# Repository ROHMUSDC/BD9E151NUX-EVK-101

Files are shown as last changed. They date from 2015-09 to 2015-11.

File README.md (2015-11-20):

# BD9E151NUX-EVK-101 Design Resource Repository
* Hardware Design Files and Documentation for the ROHM BD9E151NUX-EVK-101 EVK

----
### Description: 
* BD9E151NUX is a 28Vin max, 1.2A diode-rectification buck converter that integrated internal high-side 30V Power MOSFET
* To increase efficiency at light loads, a pulse skipping mode is automatically activated
* Furthermore, the 0uA shutdown supply current allows the device to be used in battery powered applications
* Current mode control with internal slope compensation simplifies the external component count while allowing the use of ceramic output capacitors

----
### Repository Contents
* Application Note Folder: Contains Draft Version of EVK Application Note
* Design Files: Contains Board, Gerber, Schematic, and BOM information for this EVK Board
* Measurement Reports Folder: Contains measurement testing information completed for these EVK Boards

----
### Where to Purchase?
* http://www.rohm.com/web/global/distribution/-/dinventory/BD9E151NUX-TR/sample/0

----
### DISCLAIMER
This Technical Data is protected under copyright laws.

ROHM hereby grants you a nonexclusive, nontransferable license to use this Technical Data 
as long as you abide by the terms and conditions of this DISCLAIMER. 

However, you are not authorized to sell, loan, rent, lease, redistribute or license this Technical Data, 
in whole or in part, or in modified form, to anyone.

You may modify this Technical Data to suit your specific applications, 
but the rights to derivative works and said modifications shall belong to ROHM. 

You may make copies of this Technical Data as necessary for internal use only within your company.

In any case, the latest datasheet is considered the final design guideline and represents 
the only actual performance specifications.

ROHM shall not be responsible for ensuring proper application on all computer systems.
This Technical Data is provided AS IS. ROHM makes no guarantees, either implicitly or explicitly, 
regarding its usability, functionality, accuracy, merchantability, or fitness for a specific purpose.

In addition, you shall take full responsibility for the use of any information acquired from this Technical Data. 

ROHM does not assume warranty of any kind arising from the use of this Technical Data. ACCORDINGLY, 
IN NO EVENT SHALL ROHM BE RESPONSIBLE, WHETHER THROUGH CONTRACT OR TORT LIABILITY, 
FOR ANY DAMAGES (INCLUDING BUT NOT LIMITED TO LOST PROFITS OR OTHER INCIDENTAL, CONSEQUENTAL, 
OR PUNITIVE DAMAGES) ARISING OUT OF OR IN CONNECTION WITH THE USE OR APPLICATION OF THIS Technical Data.

Furthermore, this Technical Data is subject to change without notice.

Unless otherwise expressly provided herein, ROHM does not convey any license under patent rights 
or any other intellectual property rights (including those of third parties).

ROHM is not obligated to provide maintenance or support for the Technical Data.

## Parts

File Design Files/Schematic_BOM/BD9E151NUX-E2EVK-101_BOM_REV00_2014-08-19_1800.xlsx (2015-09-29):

TITLE & REVISION HISTORY Revised: Tuesday, August 19, 2014
xxxxx Revision: 00
Bill Of Materials August 19,2014 14:56:44 | Page1
Item | Quantity | Reference | Part | PCB Footprint | DESCRIPTION | MANUFACTURER1 | MANUFACTURER1_PART# | DISTR1 | DISTR1_PART# | DNP | Provided by ROHM | Comment
1 | 1 | C1 | 0.1uF | C0603 | CAP CER 0.1UF 16V 10% X7R 0603 | Murata | GRM188R71C104KA01D | DIGIKEY | 490-1532-2-ND |  | N | Contact Murata to get free parts
2 | 2 | C2,C3 | 22uF | C1210 | CAP CER 22UF 16V 20% X7R 1210 | Murata | GRM32ER71C226ME18L | DIGIKEY | 490-4740-2-ND |  | N | Contact Murata to get free parts
3 | 1 | C6 | 10uF | C1206 | CAP CER 10UF 35V 10% X5R 1206 | Murata | GRM31CR6YA106KA12L | DIGIKEY | 490-5524-1-ND |  | N | Contact Murata to get free parts
4 | 1 | C8 | 10000pF | C0402 | CAP CER 10000PF 50V 10% X7R 0402 | Murata | GRM155R71H103KA88D | DIGIKEY | 490-4516-1-ND |  | N | Contact Murata to get free parts
5 | 1 | C9 | 0.047uF | C0402 | CAP CER 0.047UF 25V 10% X7R 0402 | Murata | GRM155R71E473KA88D | DIGIKEY | 490-3254-1-ND |  | N | Contact Murata to get free parts
6 | 1 | D1 | RSX101VA-30TR | TUMD2 | DIODE SCHOTTKY 30V 1A 2TUMD | ROHM | RSX101VA-30TR | DIGIKEY | RSX101VA-30CT-ND |  | Y
7 | 1 | D2 | SMAJ26A | DO-214AC | TVS DIODE 26VWM 42.1VC SMA | Littelfuse Inc | SMAJ26A | DIGIKEY | SMAJ26ALFCT-ND |  | N
8 | 1 | J1 | 68000-103HLF | HDR_THVT_1X3_100 | CONN HEADER VERT .100 3POS 15AU | FCI | 68000-103HLF | DIGIKEY | 609-3461-ND |  | N
9 | 1 | L1 | 15uH | SMT_10Mx10M | INDUCTOR POWER 15UH 2.2A SMD | Wurth Electronics | 7447713150 | DIGIKEY | 732-2978-6-ND |  | N | Contact WE to get free parts
10 | 1 | R1 | 12K | R0603 | RES 12K OHM 1/10W 1% 0603 SMD | ROHM | MCR03ERTF1202 | DIGIKEY | RHM12.0KCLTR-ND |  | Y
11 | 1 | R2 | 3K | R0603 | RES 3K OHM 1/10W 1% 0603 SMD | ROHM | MCR03ERTF3001 | DIGIKEY | RHM3.00KCFTR-ND |  | Y
12 | 1 | R3 | 2.7K | R0603 | RES 2.7K OHM 1/10W 1% 0603 SMD | ROHM | MCR03ERTF2701 | DIGIKEY | RHM2.7KCFDKR-ND |  | Y
13 | 2 | TP1,TP3 | TP_TH_63MIL_RED | TP_TH | TEST POINT PC MULTI PURPOSE RED | Keystone Electronics | 5010 | DIGIKEY | 5010K-ND |  | N
14 | 2 | TP2,TP4 | TP_TH_63MIL_BLK | TP_TH | TEST POINT PC MULTI PURPOSE BLK | Keystone Electronics | 5011 | DIGIKEY | 5011K-ND |  | N
15 | 1 | U1 | BD9E151NUX | VSON008X2030 | IC REG BUCK ADJ 1.2A 8VSON | ROHM | BD9E151NUX-TR | DIGIKEY | BD9E151NUXDKR-ND |  | Y
16 | 1 |  |  |  | Shunt jumper for header J1 (item #8), CONN SHUNT 2POS GOLD W/HANDLE | TE Connectivity | 881545-1 | DIGIKEY | 881545-1-ND |  | N
17 | 2 | C4,C7 |  | C0603 |  |  |  |  |  | DNP( Do Not Place)
18 | 1 | C5 |  | C0805 |  |  |  |  |  | DNP( Do Not Place)

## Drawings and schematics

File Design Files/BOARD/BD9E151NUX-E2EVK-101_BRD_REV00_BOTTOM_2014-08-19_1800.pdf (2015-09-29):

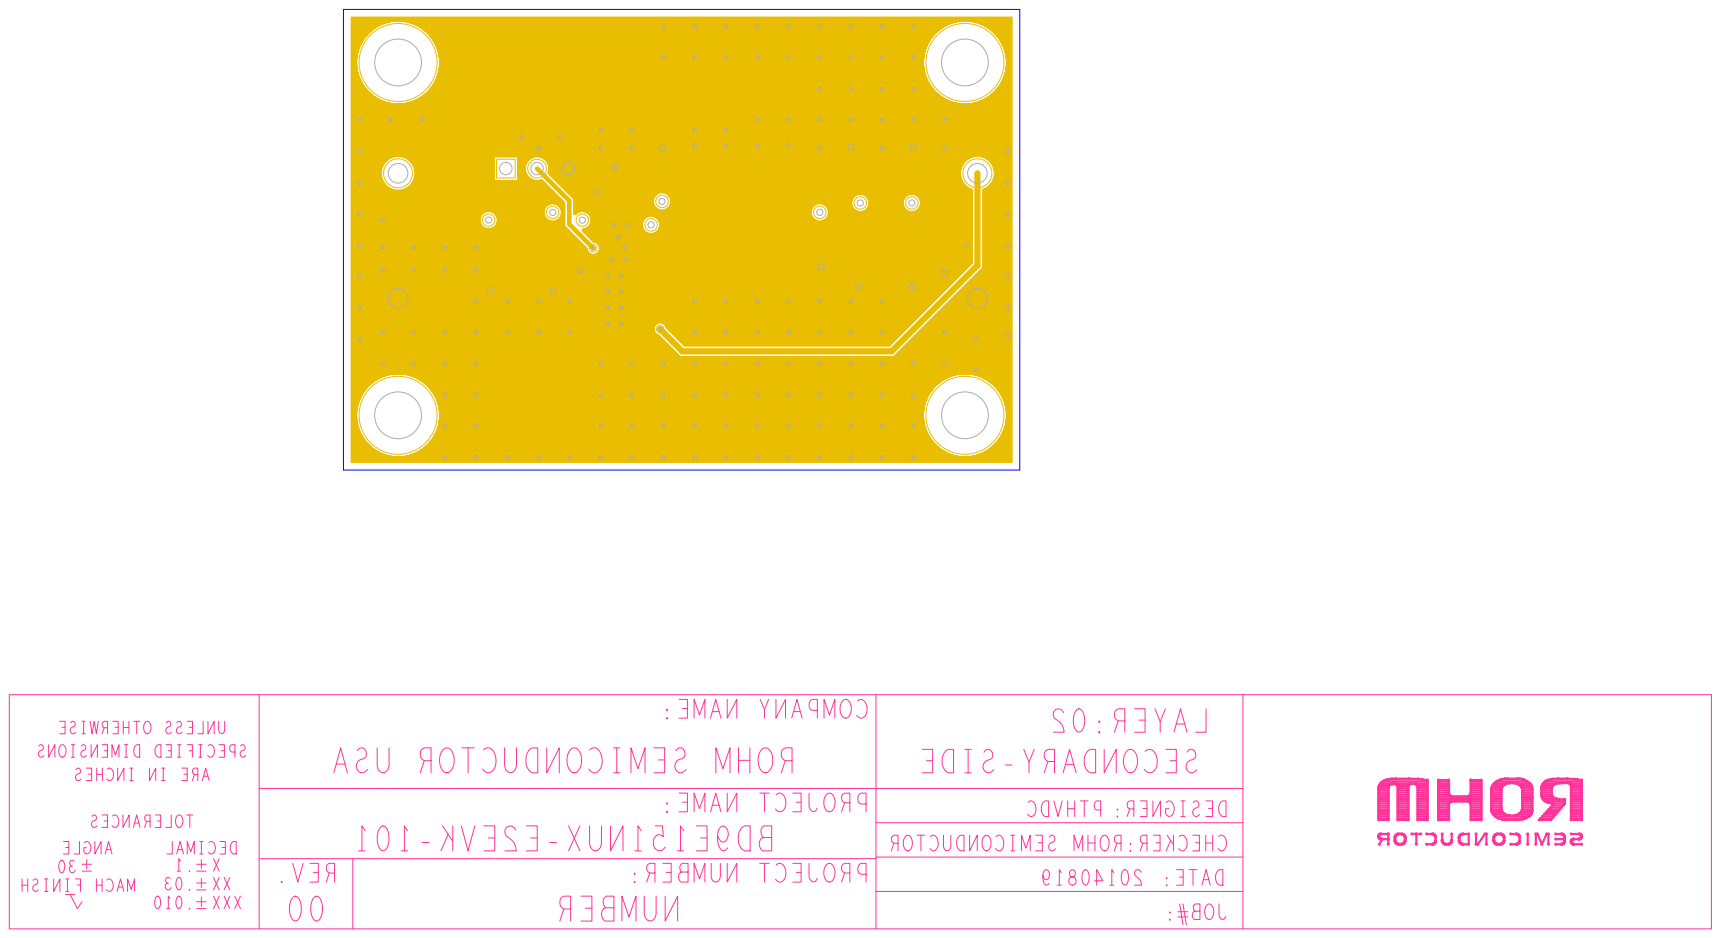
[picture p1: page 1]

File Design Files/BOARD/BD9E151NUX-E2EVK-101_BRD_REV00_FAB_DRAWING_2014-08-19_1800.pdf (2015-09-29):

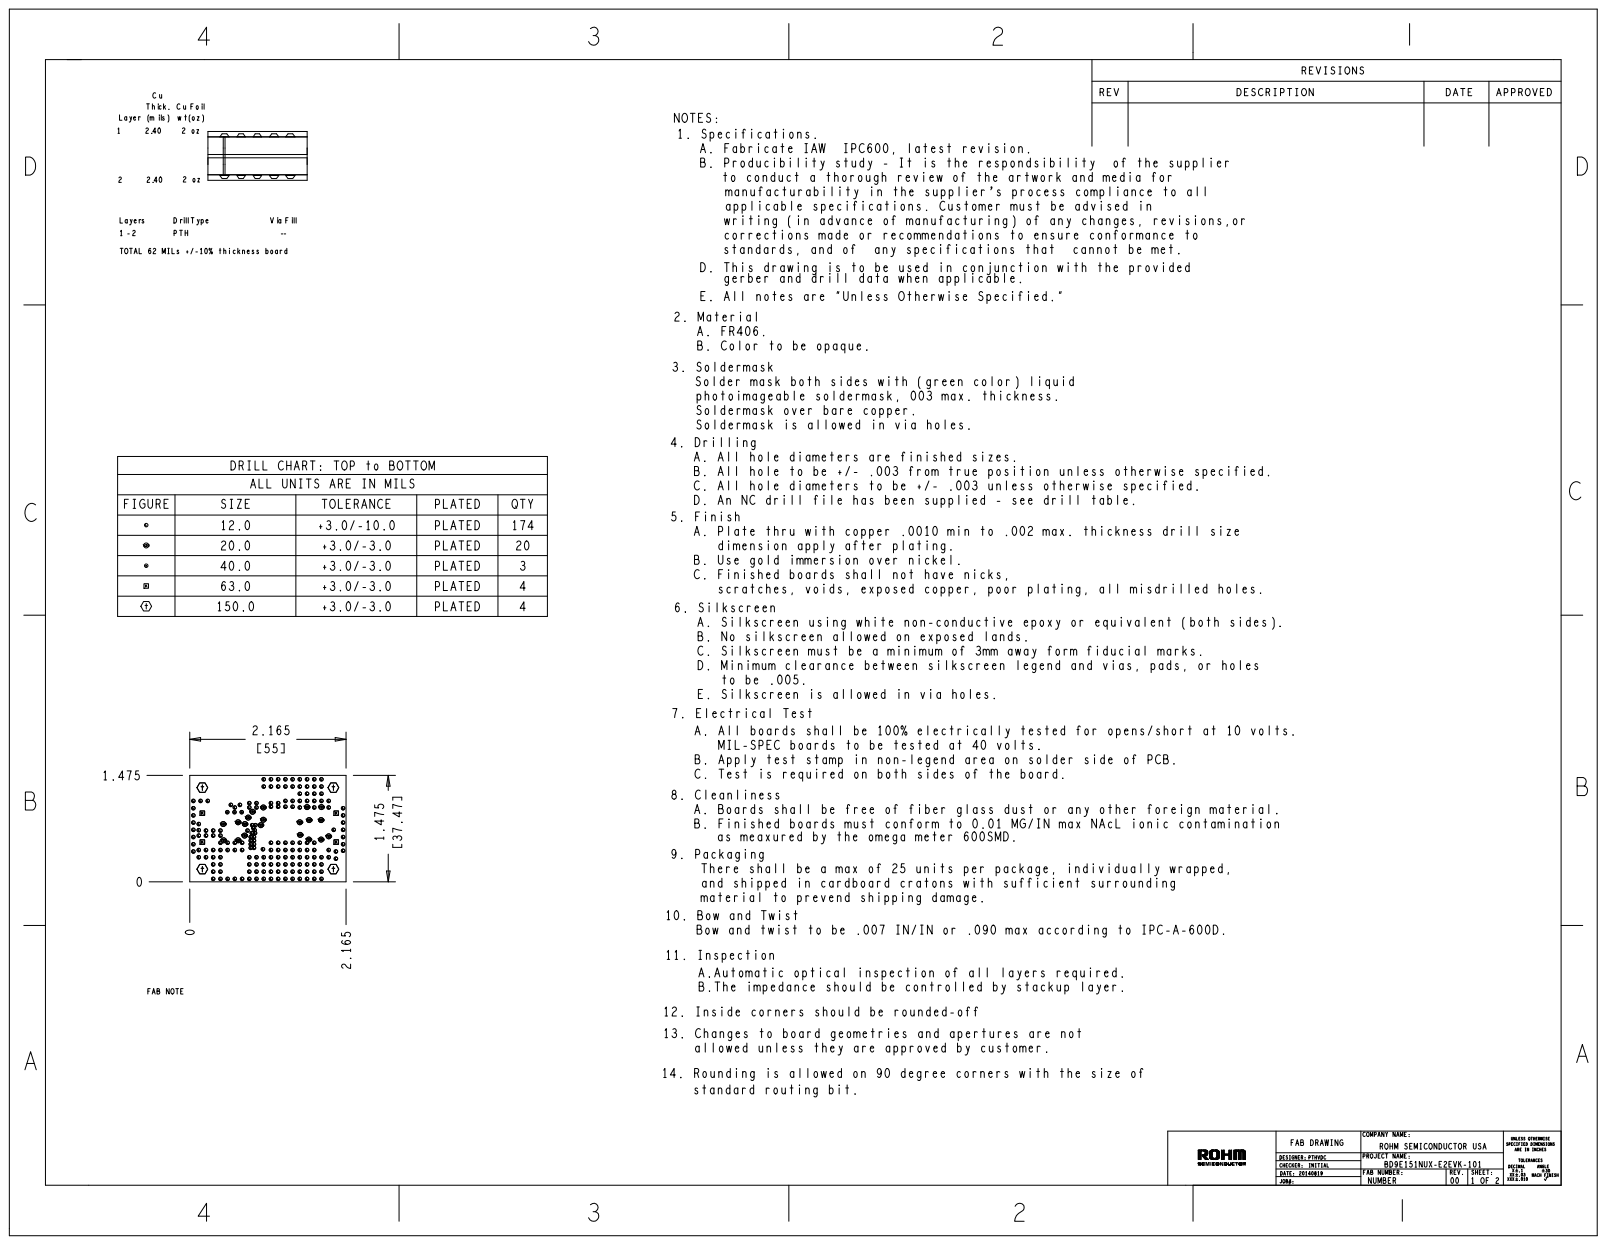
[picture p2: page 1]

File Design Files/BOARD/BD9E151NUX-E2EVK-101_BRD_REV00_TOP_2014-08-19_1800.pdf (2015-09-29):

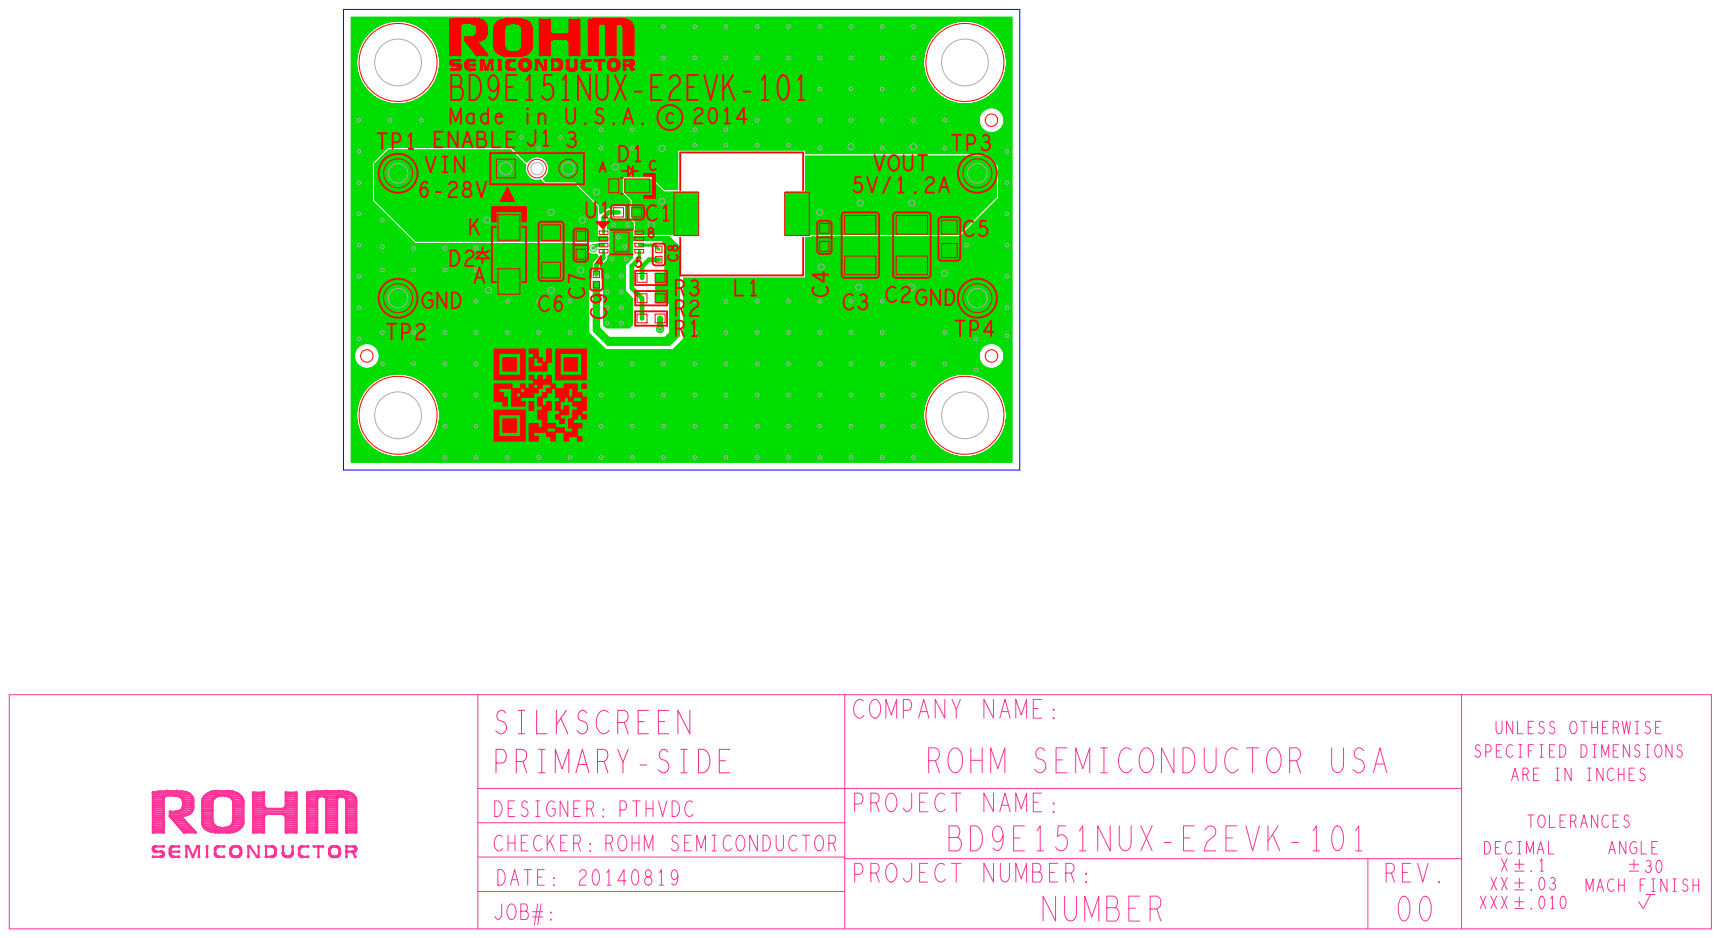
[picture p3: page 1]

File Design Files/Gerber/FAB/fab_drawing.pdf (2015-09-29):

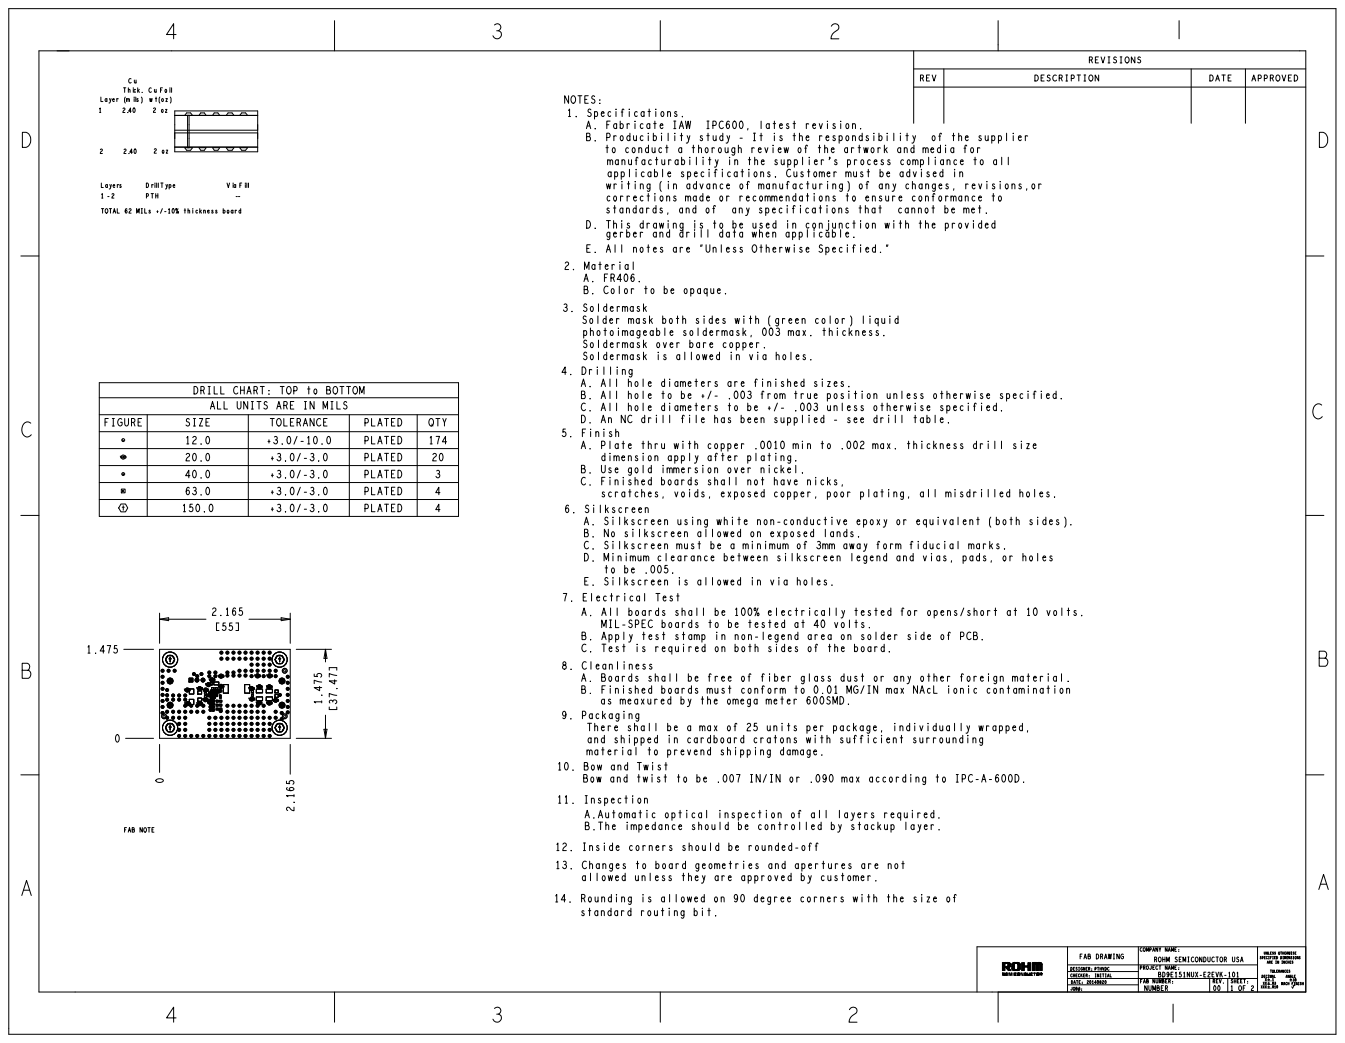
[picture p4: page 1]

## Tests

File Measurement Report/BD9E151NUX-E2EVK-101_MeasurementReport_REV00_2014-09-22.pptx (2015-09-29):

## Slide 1

PTH Solutions Confidential

BD9E151NUX-E2EVK-101 Measurement Report
September 22, 2014
Hosted by: Xuan Dang

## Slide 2

Equipment list

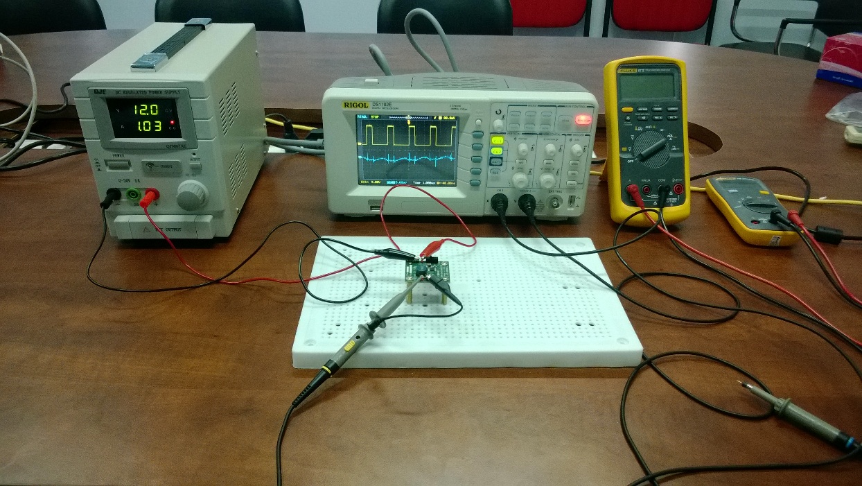
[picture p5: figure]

- Regulated DC Power Supply
  - QJE QJ3005XE (0-30V/5A).
- Multimeter:
  - Fluke 87V True RMS.
  - Fluke 106.
- Oscilloscope
  - Rigol DS1102E.
- Electronic Load
  - B&K BK8500.
- Current probe
  - RP1001C.

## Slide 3

1. Functional Test

- Test case 1 procedure with electronic load BK8500
  1. Turn on the DC Supply. Set output of the DC Supply in range from 6V to 28V and turn it off. Connect DC the Supply to: [+]VIN(TP1) and [-]GND(TP2) of evaluation board.
  2. Connect Electronic Load to: [+]VOUT(TP3) and [-]GND(TP4). Power on Electronic Load, set input of Electronic Load to 1.2A.
  3. Turn on the DC Supply.
  4. Turn on load.
  5. Move header J1 to turn EN on.
- Result:
  - VIN = 6V to 28V.
  - Vout = 0V/ 0.02A. Test fail.
The output current with electronic load BK8500 exceed ~1.75A that cause OCP (over current protection) active and shut down IC. See next slide for output current measurement.

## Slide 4

1. Functional Test (cont.)

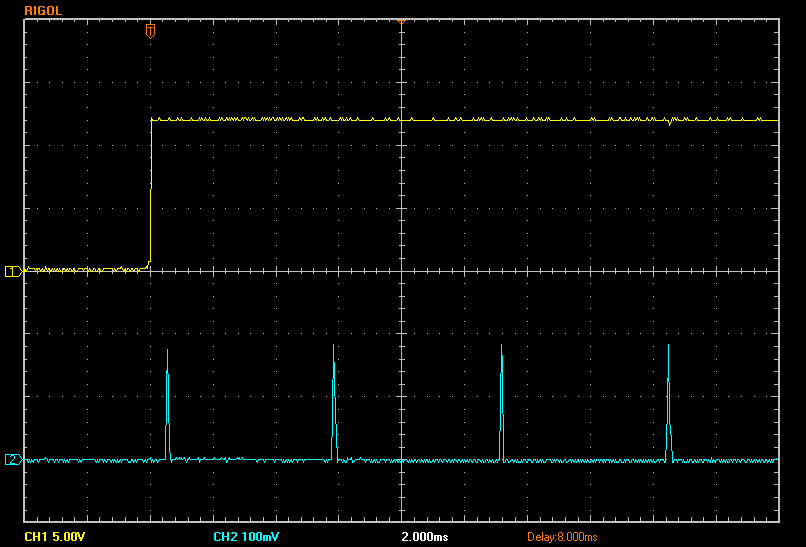
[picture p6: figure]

VEN 5V/Div. (DC)

IOUT 1A/Div. (DC)

Output current ~1.75A which cause OCP active and shut down IC

Time 2ms/Div.

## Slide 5

1. Functional Test (cont.)

- Test case 2 procedure with power resistor load 4.6 Ohms:
  1. Turn on the DC Supply. Set output of the DC Supply in range from 6V to 28V and turn it off. Connect DC the Supply to: [+]VIN(TP1) and [-]GND(TP2) of evaluation board.
  2. Connect 4.6 Ohm Resistor to: [+]VOUT(TP3) and [-]GND(TP4).
  3. Turn on the DC Supply.
  4. Move header J1 to turn EN on.
- Result:
  - VIN = 6V to 28V.
  - Vout = 4.95V/ 1.1A. Test pass.
No output current glitch with power resistor load 4.6 Ohms. So the OCP is not active like test case 1. See next slide for measurement result

9/22/2014

PTH Solutions Confidential

5

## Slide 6

1. Functional Test (cont.)

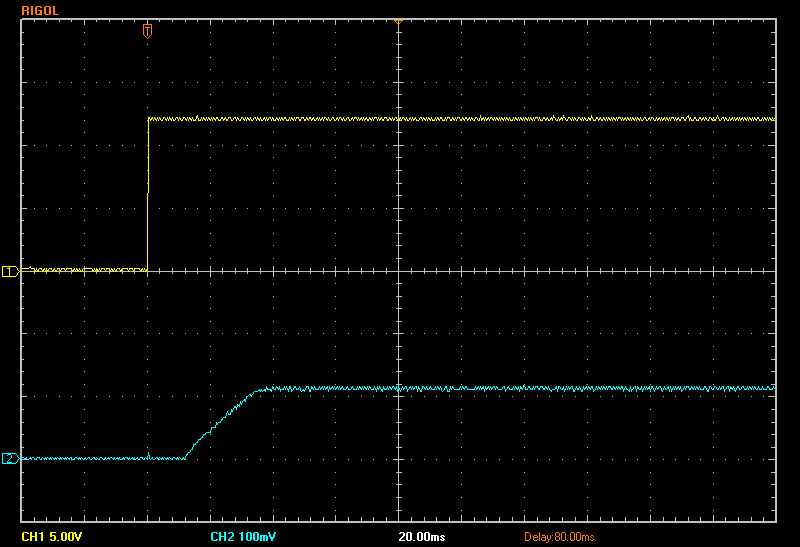
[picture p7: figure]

VEN 5V/Div. (DC)

IOUT 1A/Div. (DC)

Time 20ms/Div.

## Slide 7

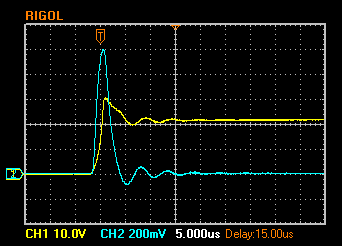
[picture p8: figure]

2. Hot Plugging Test

- Test case 1
  - VIN = 22V.
  - IOUT = 1.2A.
  - With diode D2: SMAJ20A.
- Result:
- IIN_MAX= 99.2A.
- VIN peak transient voltage is 31V > VIN Maximum Rating (30V). Test fail

VIN 10V/Div. (DC)

IIN 20A/Div. (AC)

Time 5us/Div.

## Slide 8

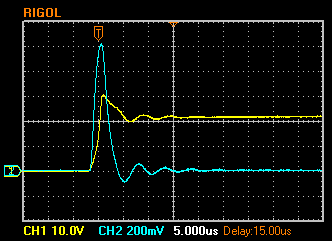
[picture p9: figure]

2. Hot Plugging Test( Cont.)

- Test case 2
  - VIN = 22V.
  - IOUT = 0A.
  - With diode D2: SMAJ20A.
- Result:
- IIN_MAX= 102A.
- VIN peak transient voltage is 31V > VIN Maximum Rating (30V). Test fail

VIN 10V/Div. (DC)

IIN 20A/Div. (AC)

Time 5us/Div.

9/22/2014

PTH Solutions Confidential

8

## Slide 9

2. Hot Plugging Test( Cont.)

- Test case 3
  - VIN = 21V.
  - IOUT =1.2A.
  - With diode D2: SMAJ22A.
- Result:
- IIN_MAX= 94.4A.
- VIN peak transient voltage is 32V > VIN Maximum Rating (30V). Test fail

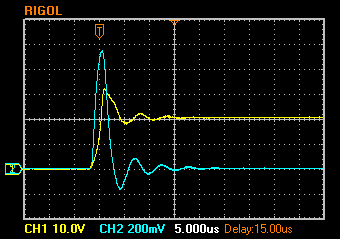
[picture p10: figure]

VIN 10V/Div. (DC)

IIN 20A/Div. (AC)

Time 5us/Div.

9/22/2014

9/22/2014

PTH Solutions Confidential

PTH Solutions Confidential

9

9

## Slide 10

3. Circuit Quiescent Current Measurement

- Test condition
  - VIN = 0-28V.
  - Room temperature 25oC.

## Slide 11

4. Efficiency Measurements

- Test condition
  - VIN = 12V.
  - VOUT = 5V.
  - With SMAJ26A.
  - Room temperature 25oC.

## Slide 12

5. Load Response Measurements

Load response characteristic
(VIN=12V, VOUT=5V, IOUT=0A → 1.2A)

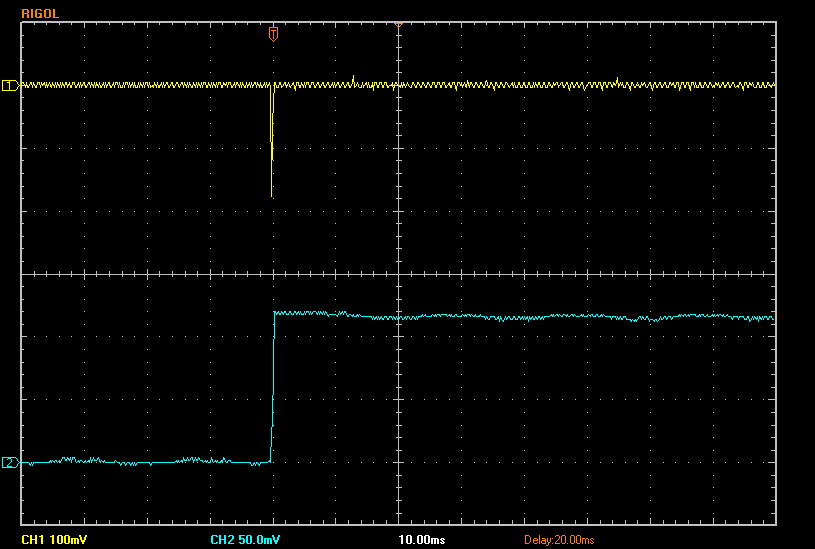
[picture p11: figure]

VOUT 100mV/Div. (AC)

IOUT 0.5A/Div. (DC)

Time 10ms/Div.

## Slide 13

5. Load Response Measurements (cont.)

Load response characteristic
(VIN=12V, VOUT=5V, IOUT=1.2A → 0A

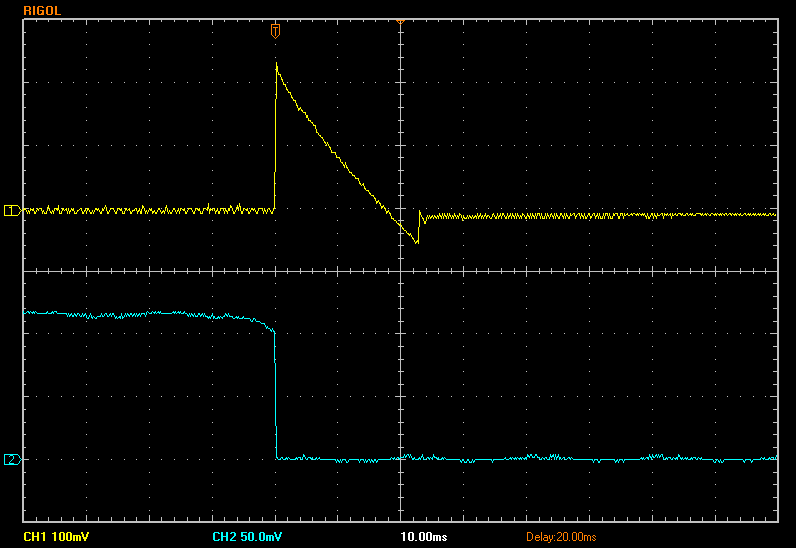
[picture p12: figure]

VOUT 100mV/Div. (AC)

IOUT 0.5A/Div. (DC)

Time 10ms/Div.

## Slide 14

6. Ripple Response Measurements

VOUT Ripple voltage
(VIN=12V, VOUT=5V, IOUT=0A)

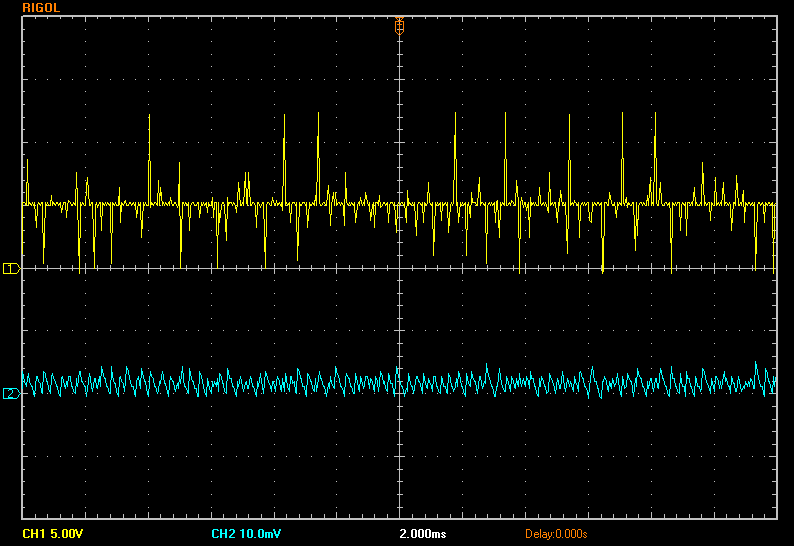
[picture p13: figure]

VSW 5V/Div. (DC)

VOUT 10mV/Div. (AC)

Time 2ms/Div.

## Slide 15

6. Ripple Response Measurements (cont.)

VOUT Ripple voltage
(VIN=12V, VOUT=5V, IOUT=1.2A

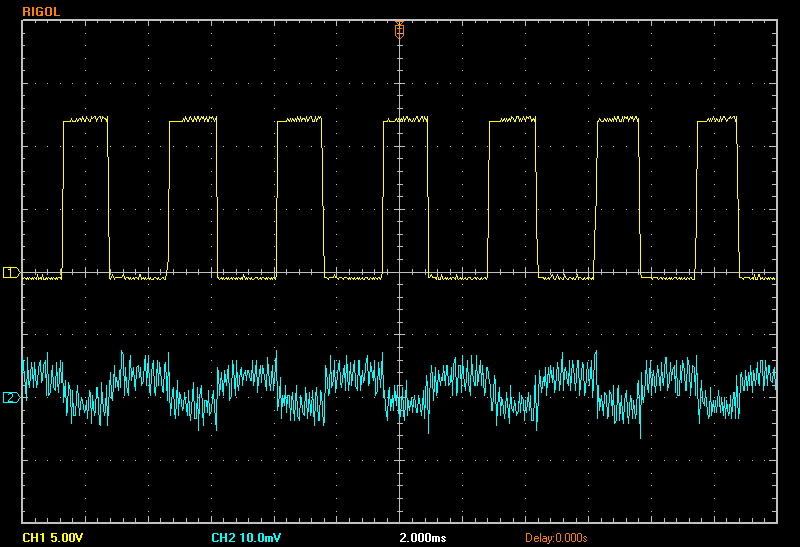
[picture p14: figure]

VSW 5V/Div. (DC)

VOUT 10mV/Div. (AC)

Time 2ms/Div.
